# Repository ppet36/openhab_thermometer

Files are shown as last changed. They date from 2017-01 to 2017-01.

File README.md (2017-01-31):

# OpenHAB thermo & humidity meter

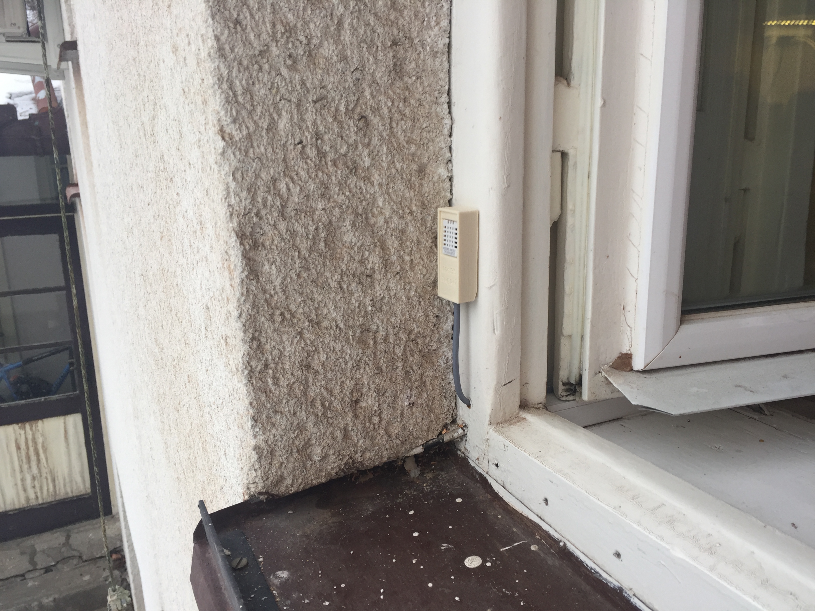
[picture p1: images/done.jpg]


This repository contains Cadsoft's Eagle schematic and PCBs as well as Arduino firmware for simple temperature and humidity meter based on ESP8266-01 and AM2302 sensor. Meter is divided into two parts; indoor part with ESP and outdoor part with sensor.

For powering unit is used cheap DC/DC converter with LM2596 from eBay (previously set to 3.3V!!!); in my case is power supply shared with motorized venetian blinds in kitchen; they have 24VDC. Switching DC/DC converter seems to be overkill, but when voltage drop is too large (in my case around 21V) linear ones generates much heat and thus this converter is economical variant.

### Indoor part schematic
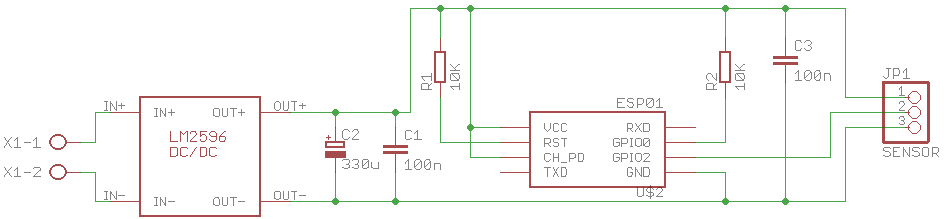
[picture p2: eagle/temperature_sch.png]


### Outdoor part schematic
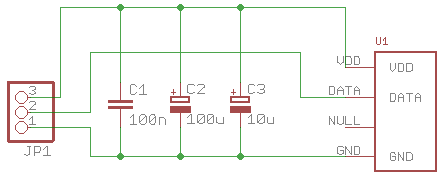
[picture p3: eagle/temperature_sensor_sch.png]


Firmware can be programmed from Arduino IDE. For compilation is needed AM library from Adafruit which can be downloaded from https://learn.adafruit.com/dht/downloads. WIFI access point and network parameters can be set in source code. After device startup is on his IP address available HTTP server which provides measured temperature and humidity values as REST services. Via HTTP server is also available simple configuration page.

PCB boards is designed as single-sided. Indoor part of thermometer is placed in rectangular electrical ducting. For outdoor part i created simple model, which is available in openscad directory.

### OpenHAB
OpenHAB definition is also very simple. You need to edit your items and sitemap files. In items file is needed to add definition of services (replace IP address with IP address of your device):
```
Number outdoorTemperature "Outdoor temperature [%.1f °C]" <temperature> { http="<[http://192.168.128.205/temperature:15000:JS(doublevalue.js)]" }
Number outdoorHumidity "Outdoor humidity [%.1f %%]" <water> { http="<[http://192.168.128.205/humidity:15000:JS(doublevalue.js)]" }
```
In short this defines two numbers, which is readed from given URLs every 15 seconds and readed values is converted using script doublevalue.js. Finally can be measured values added to your sitemap file:
```    
Text item=outdoorTemperature
Text item=outdoorHumidity
```
After successfull configuration are available measured values on OpenHAB page:
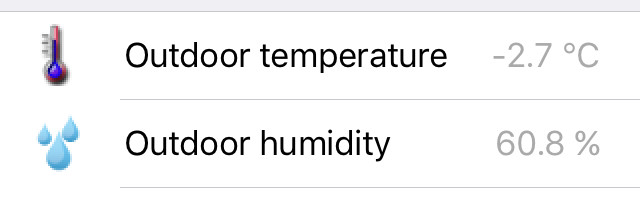
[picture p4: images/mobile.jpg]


## Some project images
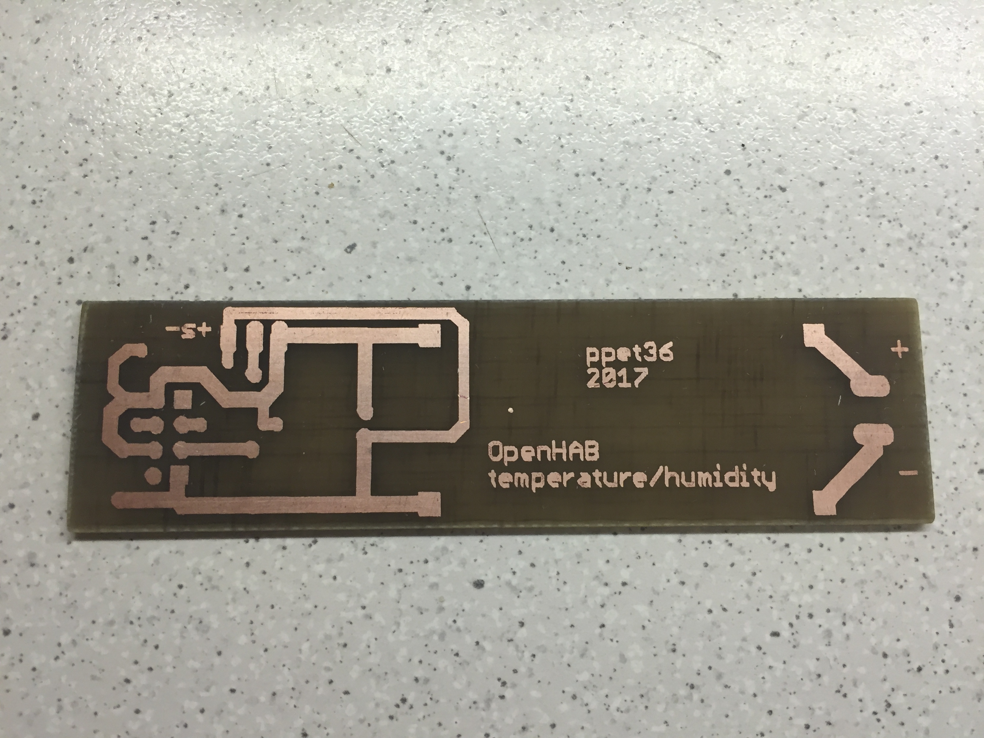
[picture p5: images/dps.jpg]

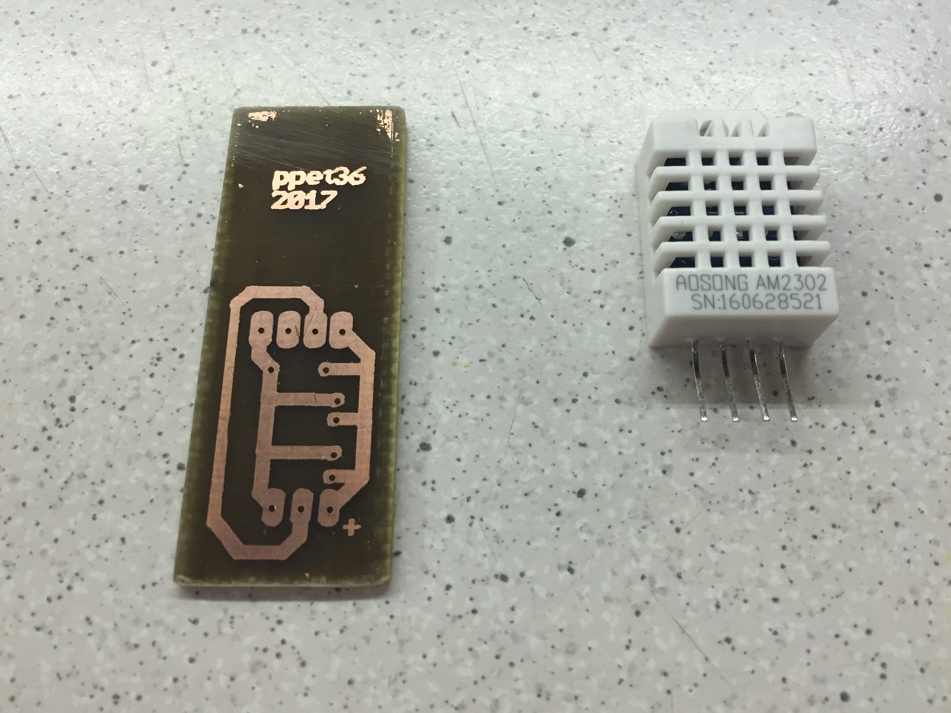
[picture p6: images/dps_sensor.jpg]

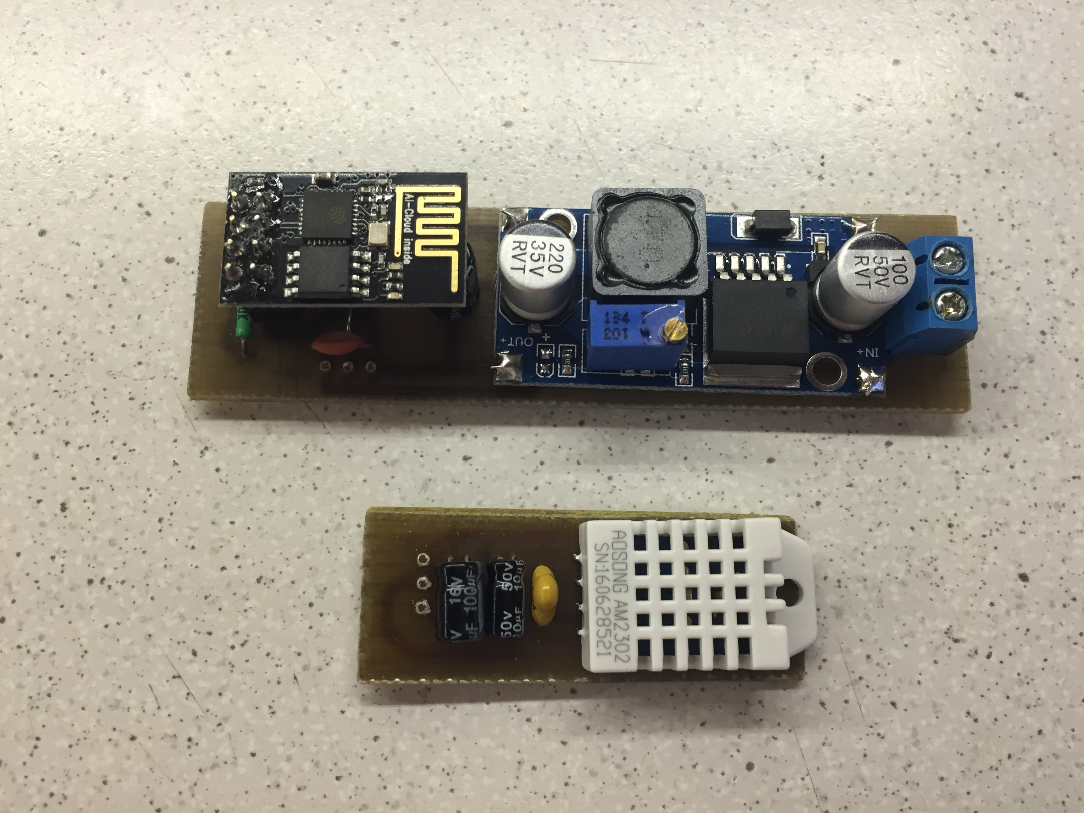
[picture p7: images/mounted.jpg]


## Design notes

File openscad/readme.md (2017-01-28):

Enclosure for outdoor part of OpenHAB thermometer.

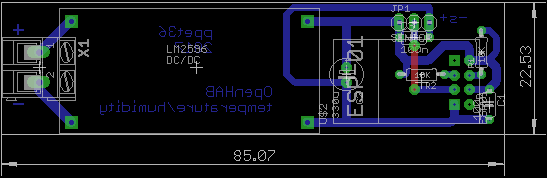
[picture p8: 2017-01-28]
eagle/temperature_brd.png

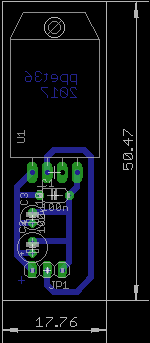
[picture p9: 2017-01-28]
eagle/temperature_sensor_brd.png

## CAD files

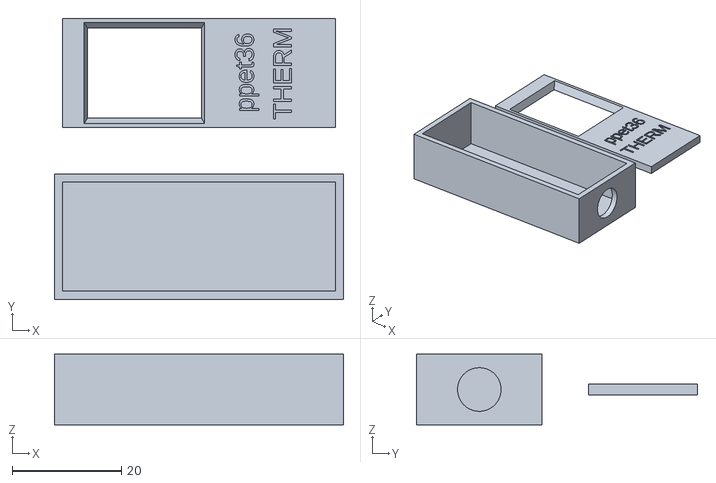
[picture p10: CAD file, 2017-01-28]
openscad/sensor.stl
53.0 x 51.5 x 13.0

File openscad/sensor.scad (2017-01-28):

$fn=50;

module spodek() {
  rotate([180,0,0])
  difference() {
    cube ([53,23,13], center=true);
    translate([0,0,-0.51]) cube ([50,20,12], center=true);
    translate([25,0,0]) rotate([90,0,90]) cylinder (d=8,h=5, center=true);
  }
}

module vrsek() {

    difference() {
      cube ([50,20,2],center=true);
      translate([-10,0,-2])
      hull() {
        cube ([20,15,1], center=true);
        translate([0,0,5]) cube ([23,20,1], center=true);
      }
    
    
    translate([10,-7.2,0.6]) rotate([0,0,90]) linear_extrude(height=1) text("ppet36",size=3.5, font="Arimo");
    translate([17,-8.5,0.6]) rotate([0,0,90]) linear_extrude(height=1) text("THERM",size=3.5, font="Arimo");
    }
}

spodek();
translate([0,30,0]) vrsek();

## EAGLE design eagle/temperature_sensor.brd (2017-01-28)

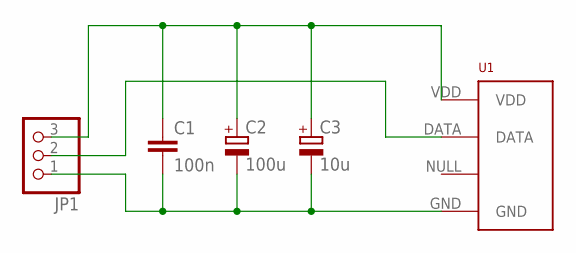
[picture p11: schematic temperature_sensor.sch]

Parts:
C1: 100n; C050-024X044
C2: 100u; E2-5
C3: 10u; E1,8-4
JP1: PINHD-1X3; 1X03
U1: RHT03_DHT-22_AM2302RA; RHT03_DHT-22/RA

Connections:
unnamed: C1.2, C2.-, C3.-, JP1.1, U1.GND
unnamed: C1.1, C2.+, C3.+, JP1.3, U1.VDD
unnamed: JP1.2, U1.DATA

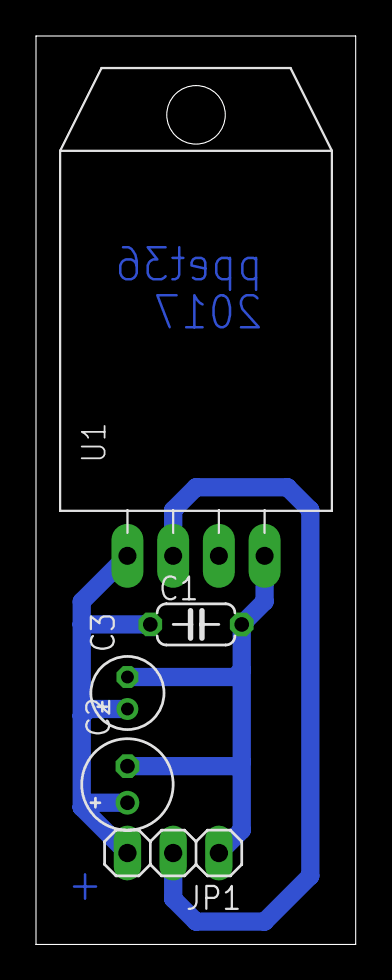
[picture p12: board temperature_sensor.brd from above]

Board: 2 copper layers, 17.8 x 50.5 mm, 5 parts (0 on the bottom side), 3 nets.

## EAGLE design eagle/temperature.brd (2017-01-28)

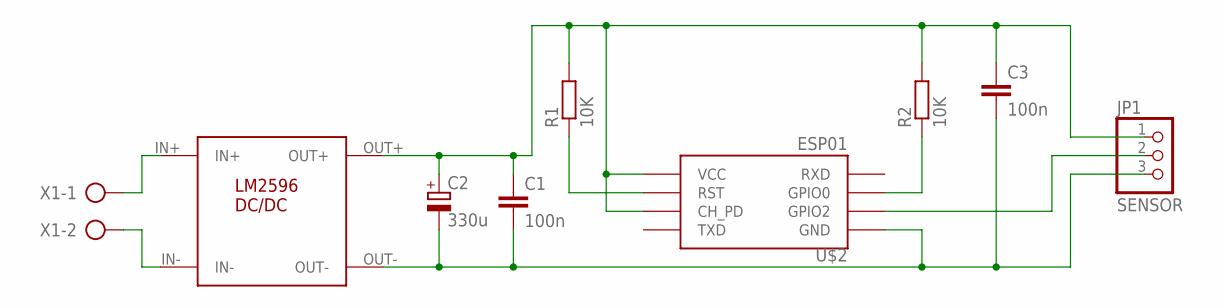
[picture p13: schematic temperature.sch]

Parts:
C1, C3: 100n; C050-024X044
C2: 330u; E2,5-6E
JP1: SENSOR; 1X03
R1, R2: 10K; 0204/7
U$1: LM2596DCDC
U$2: ESP01
X1: AK300/2

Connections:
GND: C1.2, C2.-, C3.2, JP1.3, U$1.OUT-, U$2.GND
unnamed: R2.1, U$2.GPIO0
unnamed: R1.1, U$2.RST
unnamed: U$1.IN+, X1.1
unnamed: JP1.2, U$2.GPIO2
unnamed: U$1.IN-, X1.2
VCC: C1.1, C2.+, C3.1, JP1.1, R1.2, R2.2, U$1.OUT+, U$2.CH_PD, U$2.VCC

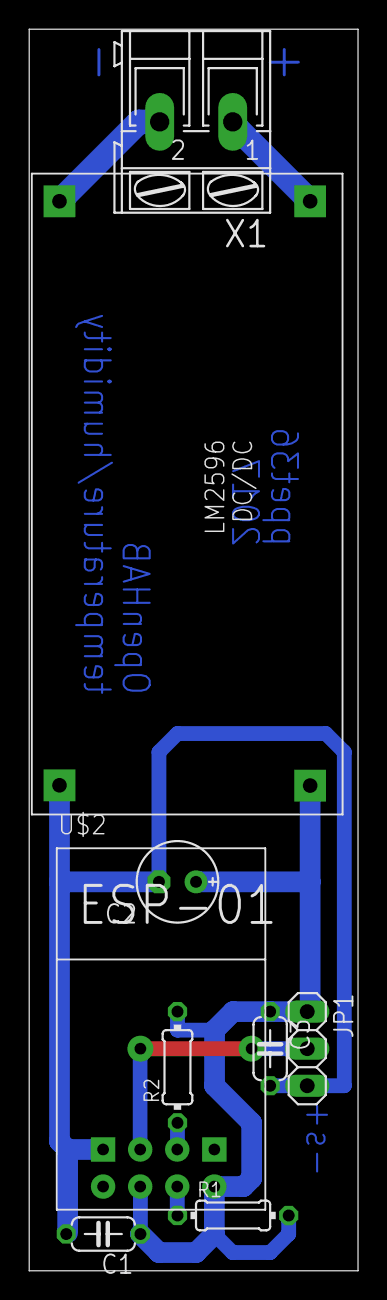
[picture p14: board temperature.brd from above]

Board: 2 copper layers, 22.5 x 85.1 mm, 9 parts (0 on the bottom side), 7 nets.

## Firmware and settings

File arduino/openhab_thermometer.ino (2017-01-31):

/**
 * Simple OpenHAB thermometer/humidity sensor based on ESP8266-01.
*/
#include <EEPROM.h>
#include <ESP8266WiFi.h>
#include <ESP8266HTTPClient.h>
#include <WiFiClient.h>
#include <ESP8266WebServer.h>
#include <DHT.h>

// Pin where is DTH22 connected
#define DHT_PIN 2


// Check URL for WIFI
#define DEFAULT_CHECK_HOST "192.168.128.100"
#define DEFAULT_CHECK_PORT 9000
#define DEFAULT_CHECK_URL  "/rest"

// Frequency of updating temperature/humidity values
#define DEFAULT_UPDATE_FREQUENCY 5

// Frequency of check whether WiFi is alive
#define DEFAULT_CHECK_FREQUENCY 60

// Local network definition; must have static IP address
#define LOCAL_IP IPAddress(192, 168, 128, 205)
#define GATEWAY IPAddress(192, 168, 128, 1)
#define SUBNETMASK IPAddress(255, 255, 255, 0)

// Local Wifi AP for connect
#define DEFAULT_WIFI_AP "******"
#define DEFAULT_WIFI_PASSWORD "******"

// Error count for reconnect WIFI
#define ERR_COUNT_FOR_RECONNECT 30
#define HTTP_READ_TIMEOUT       10000
#define HTTP_CONNECT_TIMEOUT    5000

// Local WEB server port
#define WEB_SERVER_PORT 80

// Magic for detecting empty (unconfigured) EEPROM
#define MAGIC 0xCD

/**
 * EEPROM structure.
*/
struct OhConfiguration {
  int magic;
  char apName [24];
  char password [48];
  char checkHost [20];
  unsigned int checkPort;
  char checkUrl [50];
  unsigned int checkFrequency;
  unsigned int updateFrequency;
};

// Configuration
OhConfiguration config;

// Configuration server
ESP8266WebServer *server = (ESP8266WebServer *) NULL;

// Last interaction time
long lastInteractionTime;

// Last check time
long lastCheckTime;

// Number of communication errors
int errorCount = 0;

// Last temperature.
float lastTemperature = 0.0;

// Last humidity.
float lastHumidity = 0.0;

// DHT interface
DHT dht (DHT_PIN, DHT22);

/**
 * Setup method.
*/
void setup() {
  Serial.begin (115200);
  Serial.println ("setup()");

  // Read config
  EEPROM.begin (sizeof (OhConfiguration));
  EEPROM.get (0, config);
  if (config.magic != MAGIC) {
    memset (&config, 0, sizeof (OhConfiguration));
    config.magic = MAGIC;
    updateConfigKey (config.apName, 24, String(DEFAULT_WIFI_AP));
    updateConfigKey (config.password, 48, String(DEFAULT_WIFI_PASSWORD));
    config.updateFrequency = DEFAULT_UPDATE_FREQUENCY;
    updateConfigKey (config.checkHost, 20, String (DEFAULT_CHECK_HOST));
    config.checkPort = DEFAULT_CHECK_PORT;
    updateConfigKey (config.checkUrl, 50, String(DEFAULT_CHECK_URL));
    config.checkFrequency = DEFAULT_CHECK_FREQUENCY;
  }

  reconnectWifi();
  createServer();

  lastInteractionTime = millis();
  lastCheckTime = lastInteractionTime;

  // Init interface object
  Serial.println ("Initializing DHT...");
  dht.begin();

  delay (1000);
}

/**
 * Helper routine; updates config key.
 *
 * @param c key.
 * @param len max length.
 * @param val value.
*/
void updateConfigKey (char *c, int len, String val) {
  memset (c, 0, len);
  sprintf (c, "%s", val.c_str());
}

/**
 * Reconects WIFI.
*/
void reconnectWifi() {
  Serial.println ("WiFi disconnected...");
  WiFi.disconnect();
  String hostname = String("openhab_temp/hum sensor");
  WiFi.hostname (hostname);
  WiFi.config (LOCAL_IP, GATEWAY, SUBNETMASK);
  WiFi.mode (WIFI_STA);
  delay (1000);

  Serial.print ("Connecting to "); Serial.print (WIFI_AP); Serial.print (' ');
  WiFi.begin (config.apName, config.password);
  delay (1000);
  while (WiFi.status() != WL_CONNECTED) {
    yield();
    delay (500);
    Serial.print (".");
  }
  delay (500);
  Serial.println();
  Serial.println ("WiFi connected...");
}

/**
 * Creates HTTP server.
*/
void createServer() {
  if (server) {
    server->close();
    delete server;
    server = NULL;
  }
  
  // ... and run HTTP server for setup
  server = new ESP8266WebServer (LOCAL_IP, WEB_SERVER_PORT);
  server->on ("/temperature", wsGetTemp);
  server->on ("/humidity", wsGetHumidity);
  server->on ("/tempIndex", wsGetTempIndex);
  server->on ("/", wsConfig);
  server->on ("/update", wsUpdate);
  server->on ("/reconnect", wsReconnect);
  server->begin();

  Serial.println ("Created server...");
}

/**
 * GETs temperature.
*/
void wsGetTemp() {
  server->send (200, "text/html", String(lastTemperature));
}

/**
 * GETs humidity.
*/
void wsGetHumidity() {
  server->send (200, "text/html", String(lastHumidity));
}

/**
 * GETs temperature index.
*/
void wsGetTempIndex() {
  server->send (200, "text/html", String(dht.computeHeatIndex (lastTemperature, lastHumidity, false)));
}

/**
 * Configuration page.
*/
void wsConfig() {
  yield();

  String resp = "<html><head><title>OpenHAB switch configuration</title>";
  resp += "<meta name=\"viewport\" content=\"initial-scale=1.0, width = device-width, user-scalable = no\">";
  resp += "</head><body>";
  resp += "<h1>OpenHAB temperature/humidity sensor configuration</h1>";
  resp += "<form method=\"post\" action=\"/update\" id=\"form\">";
  resp += "<table border=\"0\" cellspacing=\"0\" cellpadding=\"5\">";
  resp += "<tr><td>AP SSID:</td><td><input type=\"text\" name=\"apName\" value=\"" + String(config.apName) + "\" maxlength=\"24\"></td><td></td></tr>";
  resp += "<tr><td>AP Password:</td><td><input type=\"password\" name=\"password\" value=\"" + String(config.password) + "\" maxlength=\"48\"></td><td></td></tr>";
  resp += "<tr><td>Update sensor time [sec]:</td><td><input type=\"text\" name=\"updateFrequency\" value=\"" + String(config.updateFrequency) + "\"></td><td></td></tr>";
  resp += "<tr><td>Check host IP:</td><td><input type=\"text\" name=\"checkHost\" value=\"" + String(config.checkHost) + "\" maxlength=\"20\"></td><td></td></tr>";
  resp += "<tr><td>Check port:</td><td><input type=\"text\" name=\"checkPort\" value=\"" + String(config.checkPort) + "\" maxlength=\"5\"></td><td></td></tr>";
  resp += "<tr><td>Check URL:</td><td><input type=\"text\" name=\"checkUrl\" value=\"" + String(config.checkUrl) + "\" maxlength=\"50\"></td><td></td></tr>";
  resp += "<tr><td>Check frequency [sec]:</td><td><input type=\"text\" name=\"checkFrequency\" value=\"" + String(config.checkFrequency) + "\"></td><td></td></tr>";

  resp += "<tr><td colspan=\"3\" align=\"center\"><input type=\"submit\" value=\"Save\"></td></tr>";
  resp += "</table></form>";
  resp += "<p><a href=\"/reconnect\">Reconnect WiFi...</a></p>";
  resp += "</body></html>";

  server->send (200, "text/html", resp);
}

/**
 * Reconnects WiFi with new parameters.
*/
void wsReconnect() {
  yield();
  String resp = "<script>window.alert ('Reconnecting WiFi...'); window.location.replace ('/');</script>";
  server->send (200, "text/html", resp);
  reconnectWifi();
  createServer();
}

/**
 * Saves configuration.
*/
void wsUpdate() {
  yield();

  String apName = server->arg ("apName");
  String password = server->arg ("password");
  unsigned int updateFrequency = atoi (server->arg ("updateFrequency").c_str());
  String checkHost = server->arg ("checkHost");
  unsigned int checkPort = atoi (server->arg ("checkPort").c_str());
  String checkUrl = server->arg ("checkUrl");
  unsigned int checkFrequency = atoi (server->arg("checkFrequency").c_str());
  
  if (apName.length() > 1) {
    updateConfigKey (config.apName, 24, apName);
    updateConfigKey (config.password, 48, password);
    config.updateFrequency = constrain (updateFrequency, 1, 600);
    updateConfigKey (config.checkHost, 20, checkHost);
    config.checkPort = constrain (checkPort, 1, 65535);
    updateConfigKey (config.checkUrl, 50, checkUrl);
    config.checkFrequency = constrain (checkFrequency, 0, 30000);
  
    // store configuration
    EEPROM.begin (sizeof (OhConfiguration));
    EEPROM.put (0, config);
    EEPROM.end();
  
    String resp = "<script>window.alert ('Configuration updated...'); window.location.replace ('/');</script>";
    server->send (200, "text/html", resp);
  } else {
    server->send (200, "text/html", "");
  }
}

/**
 * Checks WIFI connection by getting check URL.
*/
void checkWiFi() {
  if ((strlen (config.checkHost) < 1) || (config.checkFrequency < 1)) {
    return;
  }

  WiFiClient client;

  // connect to OpenHAB
  Serial.print ("Connecting to http://"); Serial.print (config.checkHost); Serial.print (':'); Serial.print (config.checkPort); Serial.print (config.checkUrl); Serial.println (" ...");
  if (client.connect (config.checkHost, config.checkPort)) {
    // send request
    String req = String("GET ") + config.checkUrl + String (" HTTP/1.1\r\n")
      + String("Host: ") + String (config.checkHost) + String ("\r\nConnection: close\r\n\r\n");
    client.print (req);
    Serial.print (req);

    bool isError = false;
    
    // wait HTTP_CONNECT_TIMEOUT for response
    unsigned long connectStartTime = millis();
    while (client.available() == 0) {
      if (millis() - connectStartTime > HTTP_CONNECT_TIMEOUT) {
        errorCount++;
        isError = true;
        break;
      }

      yield();
    }

    Serial.print ("Reading response -> ");
    if (!isError) {
      // read response lines
      unsigned long readStartTime = millis();

      int ch;
      while ((ch = client.read()) != -1) {
        if (millis() - readStartTime > HTTP_READ_TIMEOUT) {
          errorCount++;
          isError = true;
          break;
        }

        yield();
      }

      Serial.println ("OK");
      
      client.stop();
    } else {
      Serial.println ("ERROR");
      client.stop();
    }
  }
}

/**
 * Loop.
*/
void loop() {
  if (server) {
    server->handleClient();
  }

  if (millis() - lastInteractionTime > config.updateFrequency * 1000L) {
    yield();
    
    float t = dht.readTemperature();
    float h = dht.readHumidity();

    if (isnan(t) || isnan(h)) {
      Serial.println("Failed to read from DHT sensor!");
    } else {
      lastTemperature = t;
      lastHumidity = h;
      
      Serial.print("Humidity: ");
      Serial.print(lastHumidity);
      Serial.print(" %\t");
      Serial.print("Temperature: ");
      Serial.print(lastTemperature);
      Serial.println(" *C ");
    }

    lastInteractionTime = millis();
  }

  if (millis() - lastCheckTime > config.checkFrequency * 1000L) {
    yield();
    
    if (WiFi.status() == WL_CONNECTED) {
      checkWiFi();
    } else {
      Serial.println ("Wifi not connected!");
      errorCount++;
    }

    // when error count reaches ERR_COUNT_FOR_RECONNECT, reconnect WiFi.
    if (errorCount > ERR_COUNT_FOR_RECONNECT) {
      errorCount = 0;
      reconnectWifi();
      createServer();
    }

    lastCheckTime = millis();
  }

  yield();
}
